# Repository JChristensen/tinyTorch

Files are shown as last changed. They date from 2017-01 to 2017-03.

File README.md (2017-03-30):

# tinyTorch #
https://github.com/JChristensen/tinyTorch  
https://github.com/JChristensen/tinyTorch-fw  
README file  
Jack Christensen Jan-2017

## Introduction ##

**tinyTorch** is a small LED flashlight controlled by an [ATtiny84A](http://www.atmel.com/devices/ATTINY84A.aspx) microcontroller. Choose white light for best illumination, or red light to preserve night vision. Eight brightness levels are selectable. The circuit can be programmed to power off automatically; two power-off intervals are available.

**tinyTorch** runs on two AA cells. Any type will work, including alkaline, standard carbon/zinc or rechargeable types (NiMH, NiCd). A boost regulator keeps the supply voltage and therefore the LED brightness constant as the batteries age. Because of the boost circuit, **tinyTorch** can run on batteries that will no longer power other devices, more nearly extracting all the energy available from the batteries. The microcontroller monitors the voltage and automatically shuts the circuit off when the batteries are exhausted to prevent leakage.

[Hardware design](https://github.com/JChristensen/tinyTorch) and [firmware](https://github.com/JChristensen/tinyTorch-fw) are available on GitHub.  
PC boards can be ordered from [OSH Park](https://www.oshpark.com/shared_projects/fUhQEilO).  
A bill of materials is available at [Mouser Electronics](https://www.mouser.com/ProjectManager/ProjectDetail.aspx?AccessID=e556f7b439) and also in the [hardware repo](https://github.com/JChristensen/tinyTorch).

## Operation ##

Press either button to turn **tinyTorch** on. The last color and brightness are remembered.
Press UP/COLOR to increase brightness; press DOWN/OFF to decrease.
Press and hold UP/COLOR to change between the white and red LEDs.
Press and hold DOWN/OFF to turn off.

To program **tinyTorch** to turn off automatically after one minute:
- Remove one battery.
- Press and hold the DOWN/OFF button.
- Insert the battery.
- Release DOWN/OFF.

To program **tinyTorch** to turn off automatically after five minutes, use the steps above but press and hold the UP/COLOR button instead.

To disable the automatic turn-off feature, use the steps above but press and hold both buttons instead.

When the batteries are exhausted, **tinyTorch** will blink the red and white LEDs alternately and then turn off. The brightness levels will be set to the minimum values. This may allow **tinyTorch** to continue to operate at a lower brightness level for a limited time but it is advisable to replace the batteries soon to prevent leakage.

## CC BY-SA ##
"tinyTorch" by Jack Christensen is licensed under [CC BY-SA 4.0](https://creativecommons.org/licenses/by-sa/4.0/).

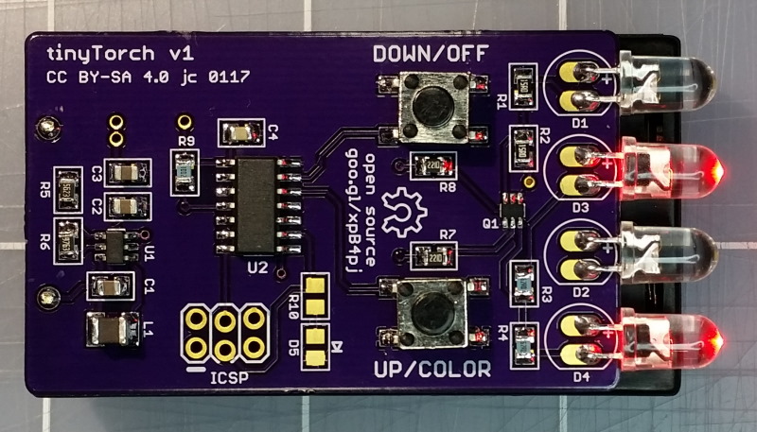
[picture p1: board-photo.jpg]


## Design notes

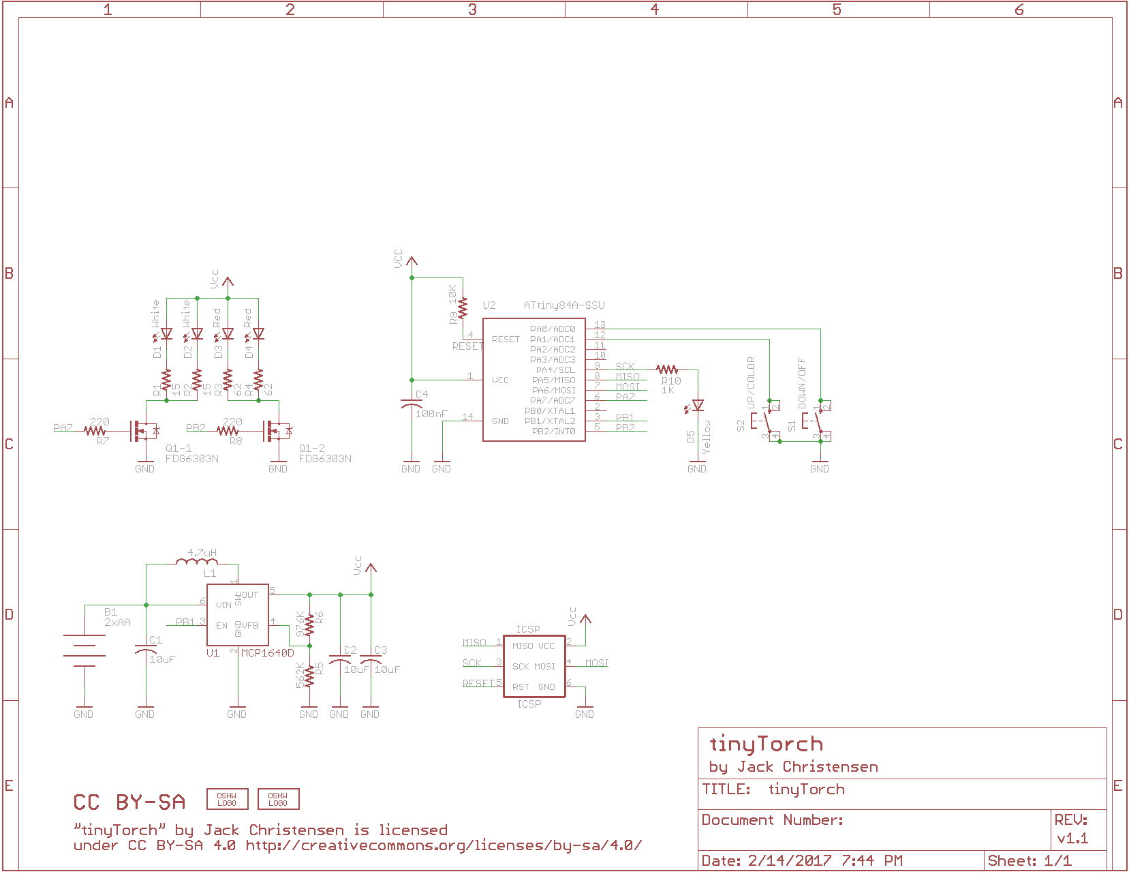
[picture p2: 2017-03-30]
schematic.png

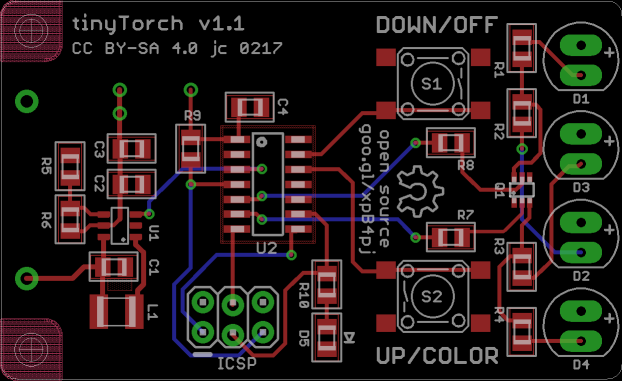
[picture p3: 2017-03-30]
board-sm.png

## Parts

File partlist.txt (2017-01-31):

Partlist

Exported from tinyTorch.sch at 1/31/2017 7:13 AM

EAGLE Version 7.5.0 Copyright (c) 1988-2015 CadSoft

Assembly variant: 

Part     Value          Device                Package                Library  Sheet

B1       2xAA           BATTERY-2AANOHOLES    KEYSTONE-2462-NO-HOLES _jc      1
C1       10uF           C-USM0805             M0805                  _jc      1
C2       10uF           C-USM0805             M0805                  _jc      1
C3       10uF           C-USM0805             M0805                  _jc      1
C4       100nF          C-USM0805             M0805                  _jc      1
D1       White          LED5MM-LONGPADS       LED5MM-OVAL            _jc      1
D2       White          LED5MM-LONGPADS       LED5MM-OVAL            _jc      1
D3       Red            LED5MM-LONGPADS       LED5MM-OVAL            _jc      1
D4       Red            LED5MM-LONGPADS       LED5MM-OVAL            _jc      1
D5       Yellow         LEDD0805A             D0805A                 _jc      1
ICSP     ICSP           AVR_SPI_PRG_62X3_LOCK 2X3_LOCK               _jc      1
L1       4.7uH          INDUCTORC1210K        C1210K                 _jc      1
Q1       FDG6303N       DUAL-MOSFET           SOT363_PHILIPS         _jc      1
R1       15             R-US_M0805            M0805                  _jc      1
R2       15             R-US_M0805            M0805                  _jc      1
R3       62             R-US_M0805            M0805                  _jc      1
R4       62             R-US_M0805            M0805                  _jc      1
R5       562K           R-US_M0805            M0805                  _jc      1
R6       976K           R-US_M0805            M0805                  _jc      1
R7       220            R-US_M0805            M0805                  _jc      1
R8       220            R-US_M0805            M0805                  _jc      1
R9       10K            R-US_M0805            M0805                  _jc      1
R10      1K             R-US_M0805            M0805                  _jc      1
S1       DOWN/OFF       10-XXSMT              TACT-SW-SMT            _jc      1
S2       UP/COLOR       10-XXSMT              TACT-SW-SMT            _jc      1
U1       MCP1640D       MCP1640               SOT23-6                _jc      1
U2       ATtiny84A-SSU  ATTINYX4SO14          SO14                   _jc      1

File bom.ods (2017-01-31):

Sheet: bom
Qty | Parts | Value | Manufacturer | Manufacturer Part No. | Notes
1 | B1 | 2xAA | Keystone | 2462
3 | C1, C2, C3 | 10uF | Murata | GRM21BR71A106KA73L
1 | C4 | 100nF | Murata | GRM21BR71E104KA01L
2 | D1, D2 | White | Cree | C503D-WAN-CCBEB151
2 | D3, D4 | Red | Lite-On | LTL2H3EZ1K
1 | D5 | Yellow | Lite-On | LTST-C171KSKT | do not populate
1 | ICSP | ICSP | TE Connectivity | 4-146262-1 | optional
1 | L1 | 4.7uH | Taiyo Yuden | CBC3225T4R7MR
1 | Q1 | FDG6303N | Fairchild/ON Semi | FDG6303N
2 | R1, R2 | 15 | Yageo | RC0805FR-0715RL
1 | R10 | 1K | Yageo | RC0805FR-071KL | do not populate
2 | R3, R4 | 62 | Yageo | RC0805FR-0762RL
1 | R5 | 562K | Yageo | RC0805FR-07562KL
1 | R6 | 976K | Yageo | RC0805FR-07976KL
2 | R7, R8 | 220 | Yageo | RC0805FR-07220RL
1 | R9 | 10K | Yageo | RC0805FR-0710KL
1 | S1, S2 | SPST Momentary Contact | Omron | B3FS-1000
1 | U1 | MCP1640D | Microchip | MCP1640DT-I/CHY
1 | U2 | ATtiny84A-SSU | Microchip | ATTINY84A-SSU

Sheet: mouser
Mouser # | Mfr. # | Manufacturer | Description | Order Qty.
603-RC0805FR-07562KL | RC0805FR-07562KL | Yageo | Thick Film Resistors - SMD 562K OHM 1% | 1
603-RC0805FR-07976KL | RC0805FR-07976KL | Yageo | Thick Film Resistors - SMD 976K OHM 1% | 1
603-RC0805FR-1310KL | RC0805FR-1310KL | Yageo | Thick Film Resistors - SMD 10K OHM 1% | 1
603-RC0805FR-071KL | RC0805FR-071KL | Yageo | Thick Film Resistors - SMD 1K OHM 1% | 0
603-RC0805FR-07220RL | RC0805FR-07220RL | Yageo | Thick Film Resistors - SMD 220 OHM 1% | 2
603-RC0805FR-0715RL | RC0805FR-0715RL | Yageo | Thick Film Resistors - SMD 15 OHM 1% | 2
603-RC0805FR-0762RL | RC0805FR-0762RL | Yageo | Thick Film Resistors - SMD 62 OHM 1% | 2
534-2462 | 2462 | Keystone Electronics | Cylindrical Battery Contacts, Clips, Holders & Springs 2 CELL AA PC HOLDER | 1
81-GRM21BR71A106KA3L | GRM21BR71A106KA73L | Murata | Multilayer Ceramic Capacitors MLCC - SMD/SMT 0805 10uF 10volts *Derate Voltage/Temp | 3
81-GRM40X104K25L | GRM21BR71E104KA01L | Murata | Multilayer Ceramic Capacitors MLCC - SMD/SMT 0805 0.1uF 25volts X7R 10% | 1
941-C503DWANCCBEB151 | C503D-WAN-CCBEB151 | Cree, Inc. | Standard LEDs - Through Hole White Round LED | 2
859-LTL2H3EZ1K | LTL2H3EZ1K | Lite-On | Standard LEDs - Through Hole Red/ Water Clear 620-630nm12000mcd | 2
963-CBC3225T4R7MR | CBC3225T4R7MR | Taiyo Yuden | Fixed Inductors 1210 4.7uH 130mOhms +/-20% 1010mA HiCur | 1
512-FDG6303N | FDG6303N | Fairchild Semiconductor | MOSFET SC70-6 N-CH 25V | 1
653-B3FS-1000 | B3FS-1000 | Omron | Tactile Switches 6X6X3.1mm 100gF | 2
579-MCP1640DT-I/CHY | MCP1640DT-I/CHY | Microchip | Voltage Regulators - Switching Regulators 500 kHz 300 mA Syn Boost Converter | 1
556-ATTINY84A-SSU | ATTINY84A-SSU | Microchip | 8-bit Microcontrollers - MCU 20MHz Ind. Grade | 1
859-LTST-C171KSKT | LTST-C171KSKT | Lite-On | Standard LEDs - SMD Yellow Clear 587nm | 0
571-4-146262-1 | 4-146262-1 | TE Connectivity | Headers & Wire Housings 06 MODII HDR DRST B/A 100W/HD | 1

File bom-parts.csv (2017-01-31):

Part | Value | Device | Package | Description | MFR | MFR-PART-NO
B1 | 2xAA | BATTERY-2AANOHOLES | KEYSTONE-2462-NO-HOLES |  | Keystone | 2462
C1 | 10uF | C-USM0805 | M0805 | CAPACITOR, American symbol
C2 | 10uF | C-USM0805 | M0805 | CAPACITOR, American symbol
C3 | 10uF | C-USM0805 | M0805 | CAPACITOR, American symbol
C4 | 100nF | C-USM0805 | M0805 | CAPACITOR, American symbol
D1 | White | LED5MM-LONGPADS | LED5MM-OVAL | LED | Cree | C503D-WAN-CCBEB151
D2 | White | LED5MM-LONGPADS | LED5MM-OVAL | LED | Cree | C503D-WAN-CCBEB151
D3 | Red | LED5MM-LONGPADS | LED5MM-OVAL | LED | Lite-On | LTL2H3EZ1K
D4 | Red | LED5MM-LONGPADS | LED5MM-OVAL | LED | Lite-On | LTL2H3EZ1K
D5 | Yellow | LEDD0805A | D0805A | LED | Lite-On | LTST-C171KYKT
ICSP | ICSP | AVR_SPI_PRG_62X3_LOCK | 2X3_LOCK | AVR ISP 6 Pin
L1 | 4.7uH | INDUCTORC1210K | C1210K | Murata #11R472C | Taiyo Yuden | CBC3225T4R7MR
LOGO1 | OSHW_LOGO_8MILX0150-NT | OSHW_LOGO_8MILX0150-NT | OSHW_8X150_NOTEXT
LOGO2 | OSHW_LOGO_10MILX0200-NT | OSHW_LOGO_10MILX0200-NT | OSHW_10X200_NOTEXT
Q1 | FDG6303N | DUAL-MOSFET | SOT363_PHILIPS | e.g. Fairchild/ON Semi FDG6303N
R1 | 15 | R-US_M0805 | M0805 | RESISTOR, American symbol
R2 | 15 | R-US_M0805 | M0805 | RESISTOR, American symbol
R3 | 62 | R-US_M0805 | M0805 | RESISTOR, American symbol
R4 | 62 | R-US_M0805 | M0805 | RESISTOR, American symbol
R5 | 562K | R-US_M0805 | M0805 | RESISTOR, American symbol
R6 | 976K | R-US_M0805 | M0805 | RESISTOR, American symbol
R7 | 220 | R-US_M0805 | M0805 | RESISTOR, American symbol
R8 | 220 | R-US_M0805 | M0805 | RESISTOR, American symbol
R9 | 10K | R-US_M0805 | M0805 | RESISTOR, American symbol
R10 | 1K | R-US_M0805 | M0805 | RESISTOR, American symbol
S1 | DOWN/OFF | 10-XXSMT | TACT-SW-SMT | OMRON SWITCH | Omron | B3FS-1000
S2 | UP/COLOR | 10-XXSMT | TACT-SW-SMT | OMRON SWITCH | Omron | B3FS-1000
U1 | MCP1640D | MCP1640 | SOT23-6
U2 | ATtiny84A-SSU | ATTINYX4SO14 | SO14

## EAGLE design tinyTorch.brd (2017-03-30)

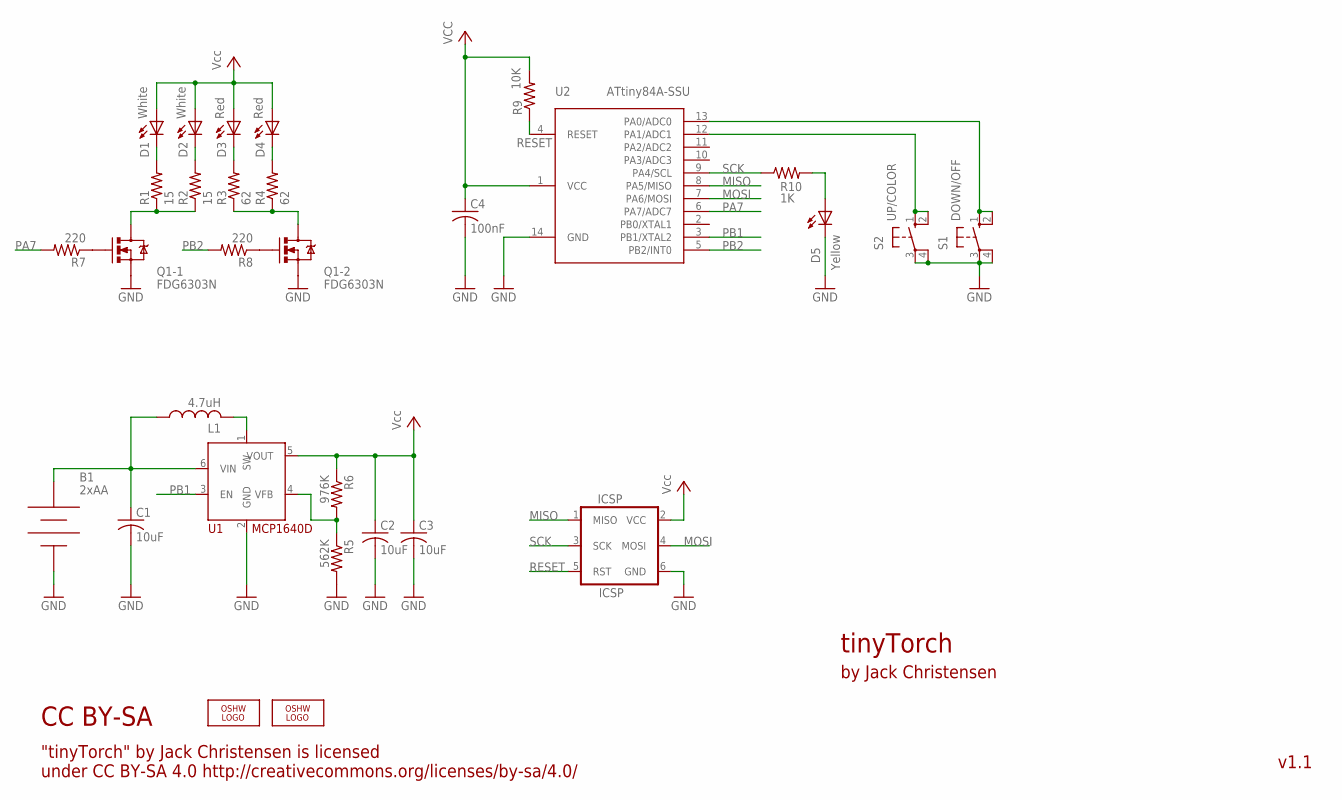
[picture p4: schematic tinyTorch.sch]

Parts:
B1: 2xAA; KEYSTONE-2462-NO-HOLES
C1, C2, C3: 10uF; M0805
C4: 100nF; M0805
D1, D2: White; LED5MM-OVAL
D3, D4: Red; LED5MM-OVAL
D5: Yellow; D0805A
ICSP: ICSP; 2X3_LOCK
L1: 4.7uH; C1210K
LOGO1: OSHW_LOGO_8MILX0150-NT; OSHW_8X150_NOTEXT
LOGO2: OSHW_LOGO_10MILX0200-NT; OSHW_10X200_NOTEXT
Q1: FDG6303N; SOT363_PHILIPS
R1, R2: 15; M0805
R3, R4: 62; M0805
R5: 562K; M0805
R6: 976K; M0805
R7, R8: 220; M0805
R9: 10K; M0805
R10: 1K; M0805
S1: DOWN/OFF; TACT-SW-SMT
S2: UP/COLOR; TACT-SW-SMT
U1: MCP1640D; SOT23-6
U2: ATtiny84A-SSU; SO14

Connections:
GND: B1.NEG, C1.2, C2.2, C3.2, C4.2, D5.K (C), ICSP.6 (GND), Q1.1 (S), Q1.4 (S), R5.2, S1.3, S1.4 (P1), S2.3, S2.4 (P1), U1.2 (GND), U2.14 (GND)
MISO: ICSP.1 (MISO), U2.8 (PA5/MISO)
MOSI: ICSP.4 (MOSI), U2.7 (PA6/MOSI)
unnamed: Q1.2 (G), R7.1
unnamed: R5.1, R6.2, U1.4 (VFB)
unnamed: Q1.5 (G), R8.1
unnamed: D1.K (C), R1.2
unnamed: D5.A, R10.2
unnamed: L1.2, U1.1 (SW)
unnamed: D4.K (C), R4.2
unnamed: D2.K (C), R2.2
unnamed: D3.K (C), R3.2
unnamed: B1.POS, C1.1, L1.1, U1.6 (VIN)
unnamed: Q1.6 (D), R1.1, R2.1
unnamed: Q1.3 (D), R3.1, R4.1
unnamed: S1.1 (S), S1.2 (S1), U2.13 (PA0/ADC0)
unnamed: S2.1 (S), S2.2 (S1), U2.12 (PA1/ADC1)
PA7: R7.2, U2.6 (PA7/ADC7)
PB1: U1.3 (EN), U2.3 (PB1/XTAL2)
PB2: R8.2, U2.5 (PB2/INT0)
RESET: ICSP.5 (RST), R9.1, U2.4 (RESET)
SCK: ICSP.3 (SCK), R10.1, U2.9 (PA4/SCL)
VCC: C2.1, C3.1, C4.1, D1.A, D2.A, D3.A, D4.A, ICSP.2 (VCC), R6.1, R9.2, U1.5 (VOUT), U2.1 (VCC)

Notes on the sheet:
"tinyTorch" by Jack Christensen is licensed under CC BY-SA 4.0 http://creativecommons.org/licenses/by-sa/4.0/
CC BY-SA
tinyTorch
by Jack Christensen
v1.1

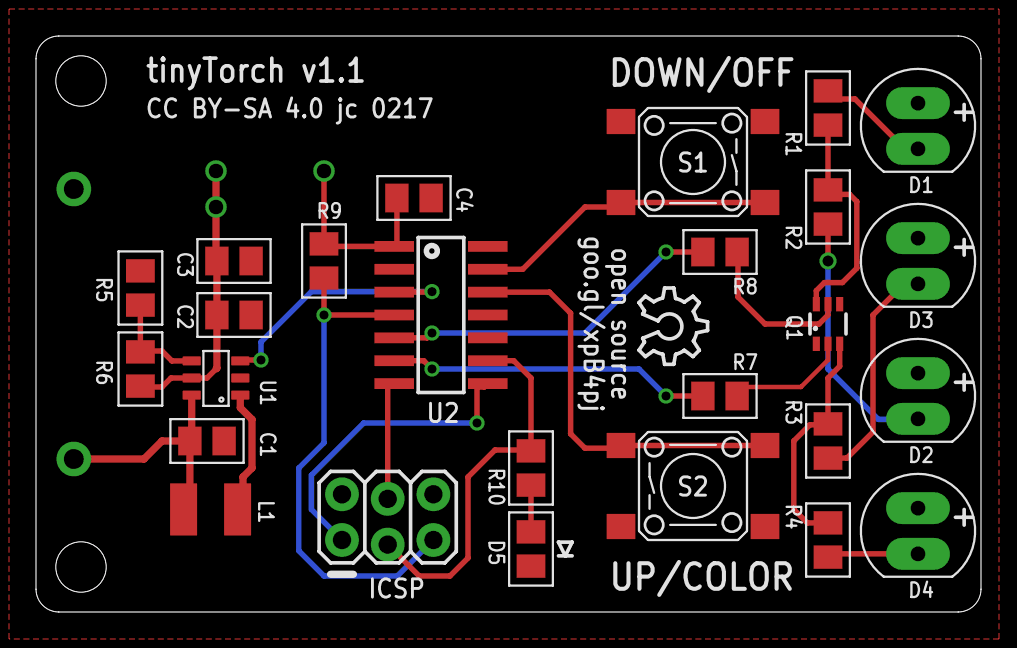
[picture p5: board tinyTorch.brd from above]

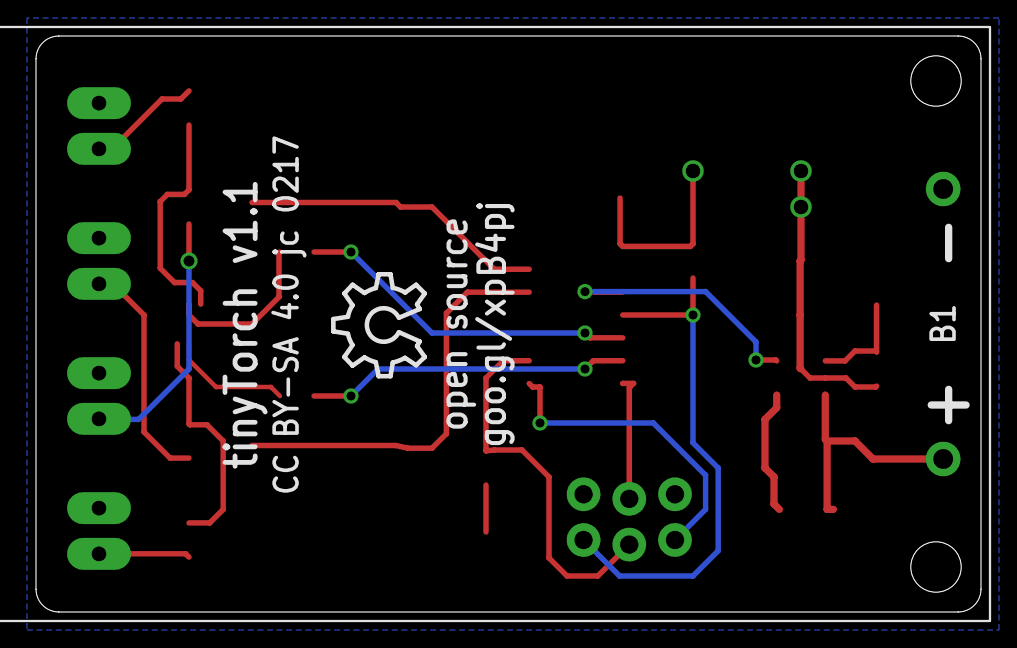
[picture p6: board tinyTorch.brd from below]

Board: 2 copper layers, 52.5 x 32.0 mm, 29 parts (2 on the bottom side), 23 nets.

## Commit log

2017-01-30 Initial commit.
    [tinyTorch.brd, tinyTorch.sch]
2017-01-31 v1 as sent to fab.
    [bom-parts.csv, bom-values.csv, tinyTorch.brd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]
2017-01-31 Tweak resistor values.
    [bom-parts.csv, bom-values.csv, tinyTorch.brd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]
2017-01-31 Update doc, bom, small board image.
    [bom.ods]
2017-02-04 Update README, board and schematic images.
2017-02-14 Add board photo.
2017-03-30 Minor board layout tweaks.
    [tinyTorch.brd, tinyTorch.sch]

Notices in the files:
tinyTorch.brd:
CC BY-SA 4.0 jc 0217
